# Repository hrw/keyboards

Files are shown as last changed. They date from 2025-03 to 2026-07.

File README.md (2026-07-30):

Here I plan to keep information about keyboards I worked on.

# [Alicja v1](alicja-v1/)

Yet another fork of fork of fork with Alice like layout.

[Blog post](https://marcin.juszkiewicz.com.pl/2025/03/09/i-built-my-first-mechanical-keyboard/)

Keyboard features:

- Handwired
- two encoders
- UltimatePico as MCU
- QMK with VIA.

Built only one copy. Dead keyboard, dead project.

# [Alicja v2](alicja-v2/)

[Blog post](https://marcin.juszkiewicz.com.pl/2026/07/29/new-keyboard-alicja-v2/)

Keyboard features:

- PCB
- hotswap
- encoder
- 5-way switch
- stabilisers
- RP2040 Stamp as MCU
- QMK with VIA
- connector with spare GPIO lines and power

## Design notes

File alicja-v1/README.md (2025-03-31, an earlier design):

# Alicja

First was TGR Alice, then [@FateNozomi](https://github.com/FateNozomi) created [Arisu](https://github.com/FateNozomi/arisu-pcb).
Next was [@floookay](https://github.com/floookay) with his [Adelheid](https://github.com/floookay/adelheid).

Then I took his keyboard and modified into what I call Alicja (Alice in Polish).

## First prototype

[Blog: "I built my first mechanical keyboard"](https://marcin.juszkiewicz.com.pl/2025/03/09/i-built-my-first-mechanical-keyboard/)

As simple as possible:
- 3d printed switch plate (two pieces mounted with each other)
- no PCB, no case
- UltimatePico as controller
- Redragon brown switches
- mix of keycaps from Aliexpress and random keyboards
- no stabilizers

### Photos

Capslock key is mapped as Fn.

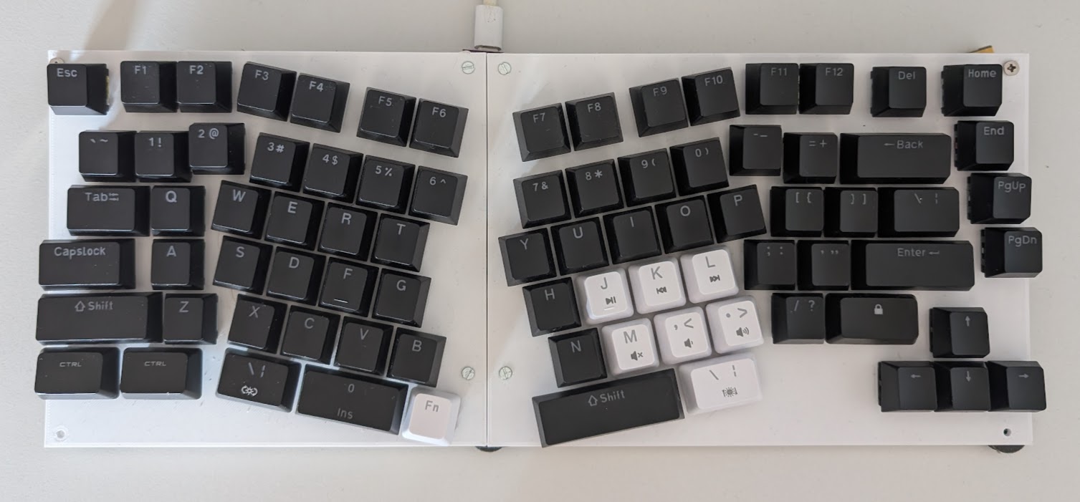
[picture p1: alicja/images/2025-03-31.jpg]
alicja

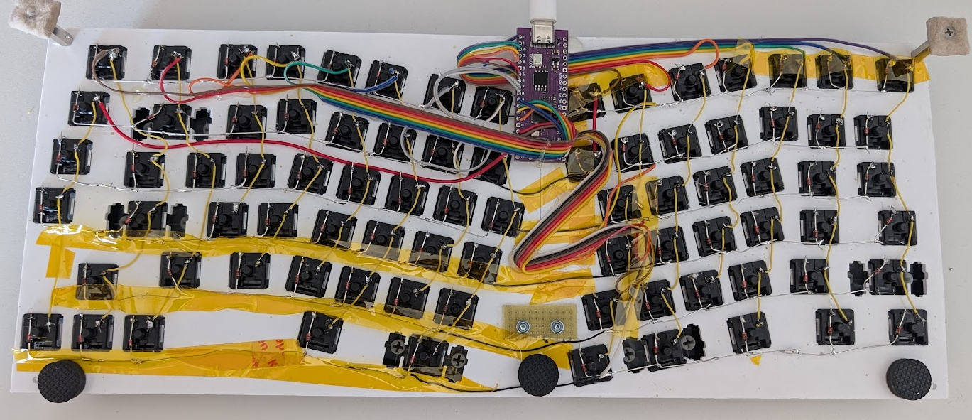
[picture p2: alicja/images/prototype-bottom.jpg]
bottom


### Changes compared to Adelheid

I did some changes to Adelheid keyboard layout:

- added 1.5u Meta key
- 2u Backspace
- 1.5u Backslash

[Keyboard Layout Editor](https://www.keyboard-layout-editor.com/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'&_c=%23777777&f:3&w:2.25%3B&=%E2%86%B5%20Enter%3B&@_c=%23aaaaaa&w:2.25%3B&=%E2%87%A7%20Shift&_c=%23cccccc&f:5%3B&=Z&_x:10.2&f:4%3B&=%3F%0A%2F%2F&_c=%23aaaaaa&f:3&w:1.75%3B&=%E2%87%A7%20Shift%3B&@_y:-0.75&x:16.45&c=%23777777&f:6%3B&=%E2%86%91%3B&@_y:-0.25&c=%23aaaaaa&f:3&w:1.5%3B&=Control&_w:1.5%3B&=Meta%3B&@_y:-0.75&x:15.45&c=%23777777&f:6%3B&=%E2%86%90&=%E2%86%93&=%E2%86%92%3B&@_rx:10&y:0.25&x:-7.5&c=%23cccccc&f:3%3B&=F2&_x:9.5%3B&=F11%3B&@_y:0.09999999999999987&x:-7.25&f:4%3B&=%2F@%0A2&_x:8.95%3B&=%2F_%0A-%3B&@_r:12&rx:8.5&ry:3.5&y:-2.25&x:-5.35&f:3%3B&=F3&=F4&_x:0.25%3B&=F5&=F6%3B&@_y:0.25&x:-4.85&f:4%3B&=%23%0A3&=$%0A4&=%25%0A5&=%5E%0A6%3B&@_x:-5.35&f:5%3B&=W&=E&=R&=T%3B&@_x:-5.1%3B&=S&=D&_n:true%3B&=F&=G%3B&@_x:-4.6%3B&=X&=C&=V&=B%3B&@_x:-4.6&c=%23aaaaaa&f:3&w:1.5%3B&=Alt&_c=%23cccccc&p=SPACE&a:7&w:2%3B&=&_c=%23aaaaaa&a:4%3B&=Fn%3B&@_r:-12&ry:3.25&y:-2.05&x:0.5500000000000007&c=%23cccccc%3B&=F7&=F8&_x:0.25%3B&=F9&=F10%3B&@_y:0.25&x:0.3000000000000007&f:4%3B&=%2F&%0A7&=*%0A8&=(%0A9&=)%0A0%3B&@_x:-0.1999999999999993&f:5%3B&=Y&=U&=I&=O&=P%3B&@_x:0.05000000000000071%3B&=H&_n:true%3B&=J&=K&=L%3B&@_x:0.3000000000000007%3B&=N&=M&_f:4%3B&=%3C%0A,&=%3E%0A.%3B&@_x:-0.1999999999999993&a:7&f:3&w:2.75%3B&=&_c=%23aaaaaa&a:4&w:1.5%3B&=Alt%20Gr)

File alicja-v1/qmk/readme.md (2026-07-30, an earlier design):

# Alicja

Alicja

*Yet another clone of Alice/Arisu/Adelheid.*

* Keyboard Maintainer: [Marcin Juszkiewicz](https://marcin.juszkiewicz.com.pl/)
* Hardware Supported: *I used Ultimate Pico, other RP2040 should be fine*
* Hardware Availability: *DIY*

Make example for this keyboard (after setting up your build environment):

    make alicja:default

See the [build environment setup](https://docs.qmk.fm/#/getting_started_build_tools)
and the [make instructions](https://docs.qmk.fm/#/getting_started_make_guide)
for more information.
Brand new to QMK? Start with our [Complete Newbs Guide](https://docs.qmk.fm/#/newbs).
ttps://docs.qmk.fm/#/newbs).

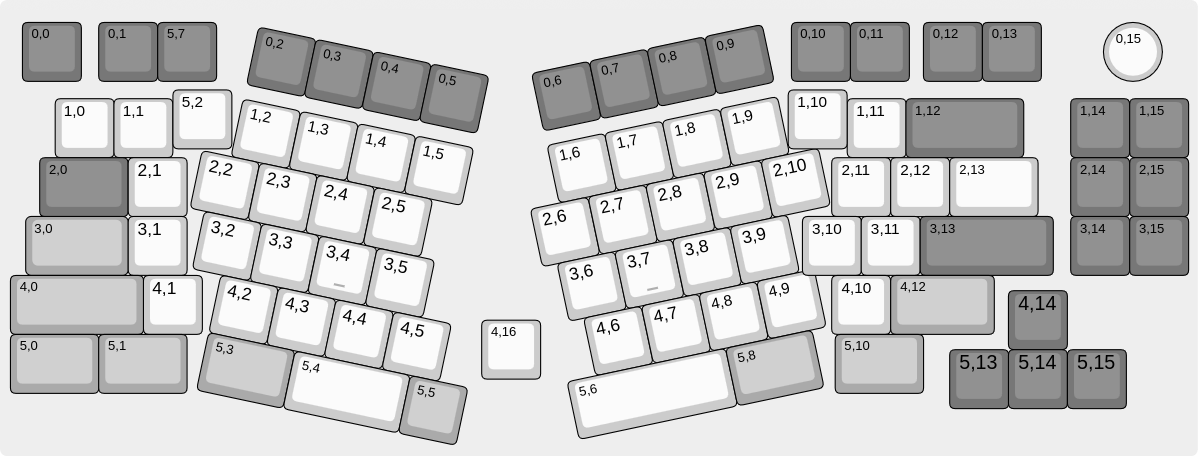
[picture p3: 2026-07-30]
alicja-v2/kle-ng/kle-layout-internal.png

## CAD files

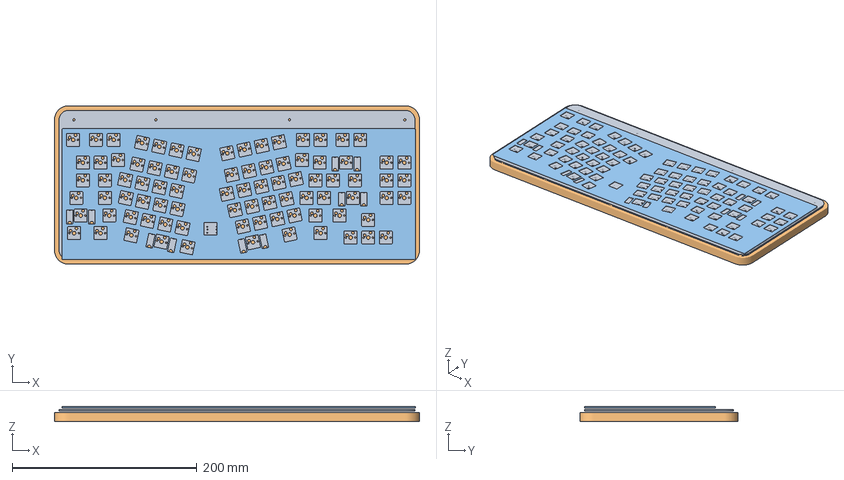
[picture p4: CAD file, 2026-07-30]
alicja-v2/case/Alicja v2.FCStd
394.8 x 171.3 x 16.5 mm
Pcb_63e7
keyboard-plate

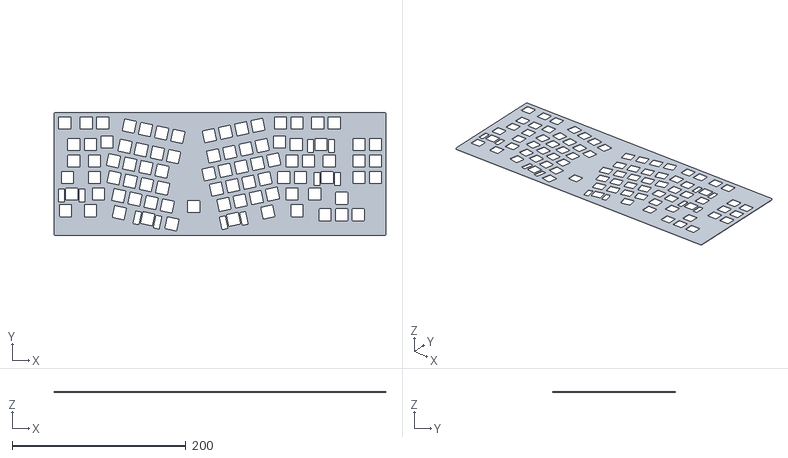
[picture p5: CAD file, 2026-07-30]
alicja-v2/kle-ng/keyboard-plate.stl
382.5 x 141.4 x 1.50

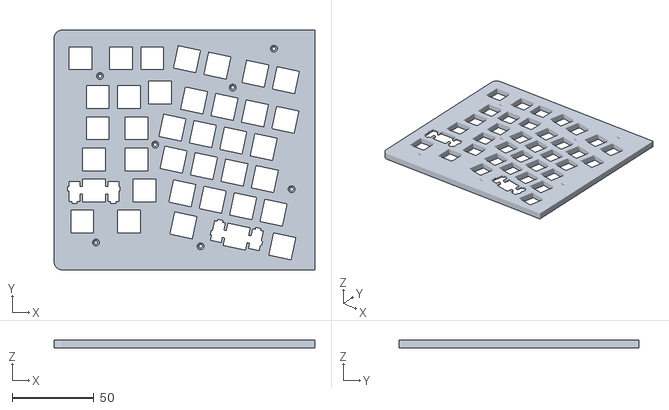
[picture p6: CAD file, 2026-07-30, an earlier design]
alicja-v1/case/drugie podejście/lewa.stl
159.9 x 147.0 x 5.00

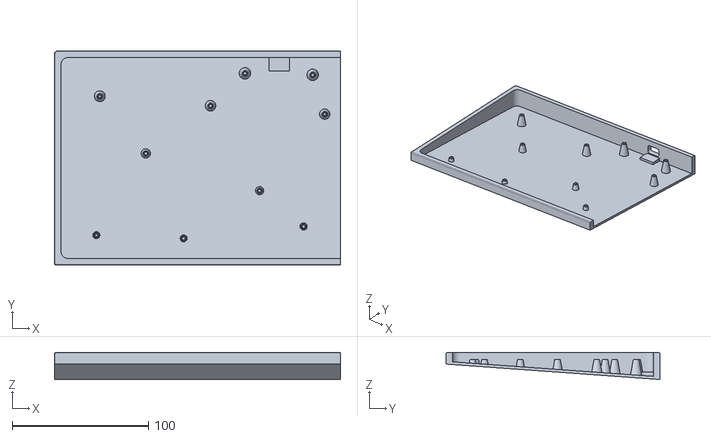
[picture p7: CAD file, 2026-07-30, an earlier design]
alicja-v1/case/drugie podejście/dol - lewa.stl
209.9 x 157.0 x 19.8

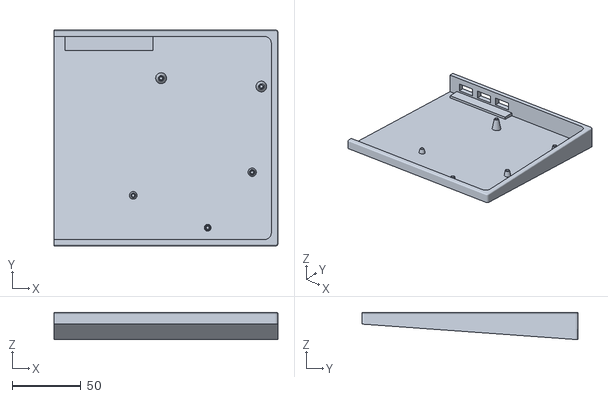
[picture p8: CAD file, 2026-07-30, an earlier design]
alicja-v1/case/drugie podejście/dol - prawa.stl
162.6 x 157.0 x 19.8

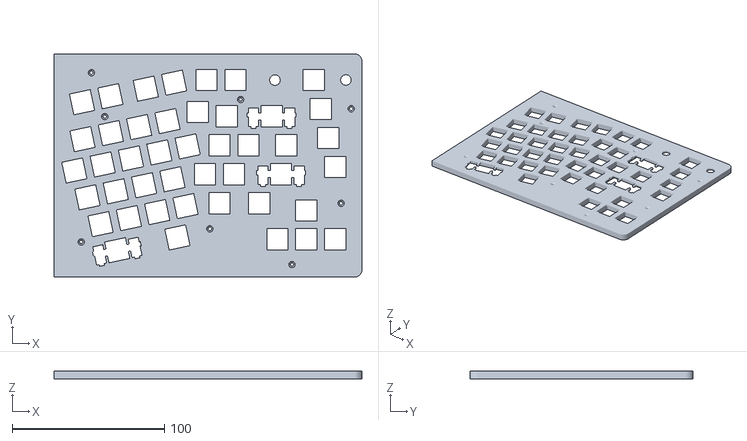
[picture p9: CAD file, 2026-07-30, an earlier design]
alicja-v1/case/drugie podejście/prawa.stl
202.6 x 147.0 x 5.00

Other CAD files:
alicja-v2/kle-ng/keyboard-plate.dxf

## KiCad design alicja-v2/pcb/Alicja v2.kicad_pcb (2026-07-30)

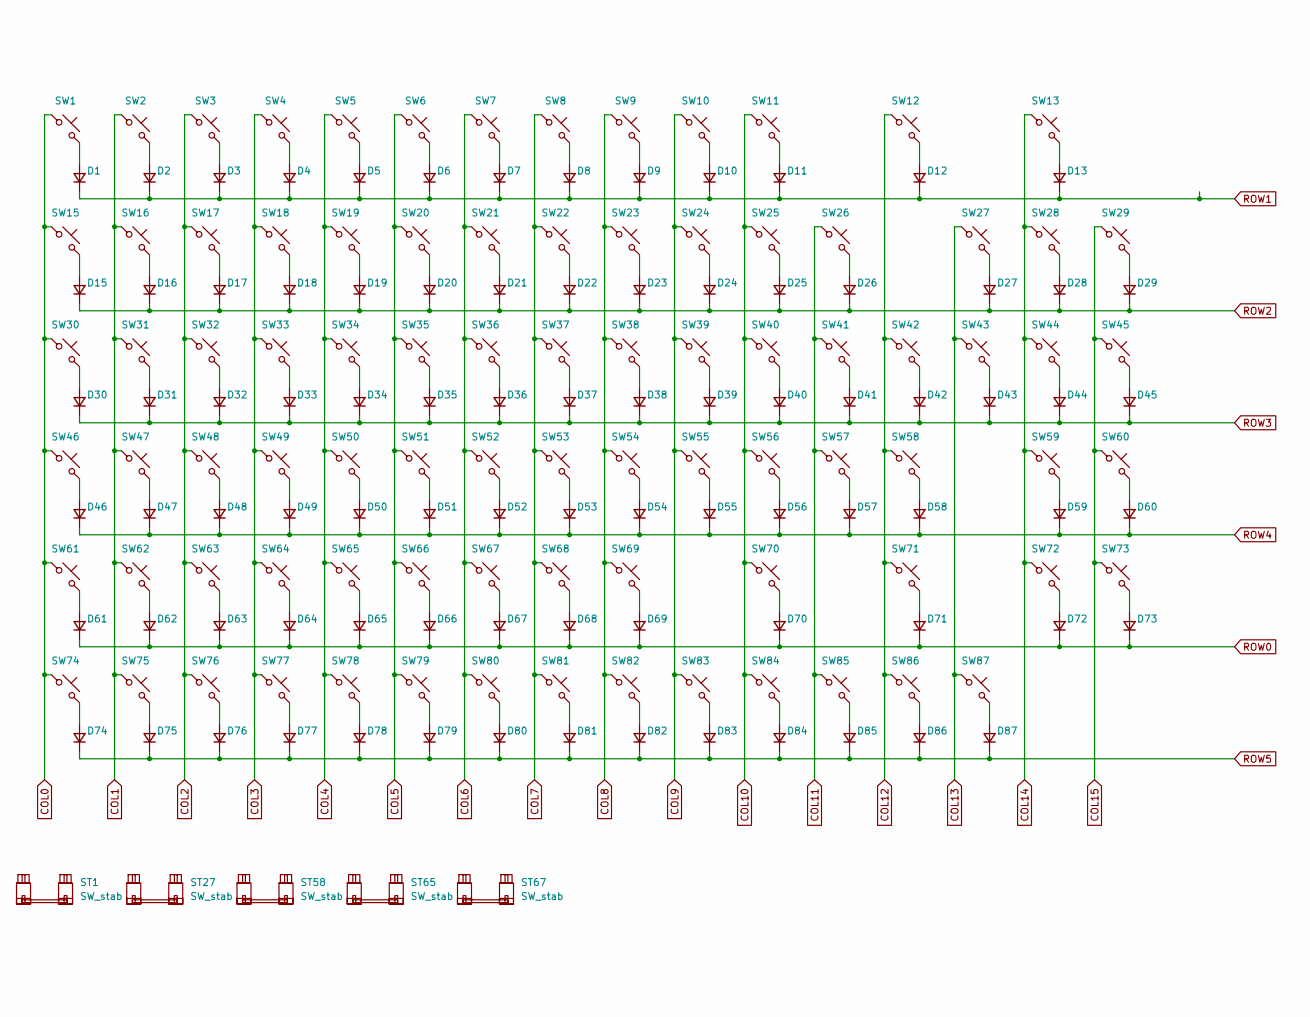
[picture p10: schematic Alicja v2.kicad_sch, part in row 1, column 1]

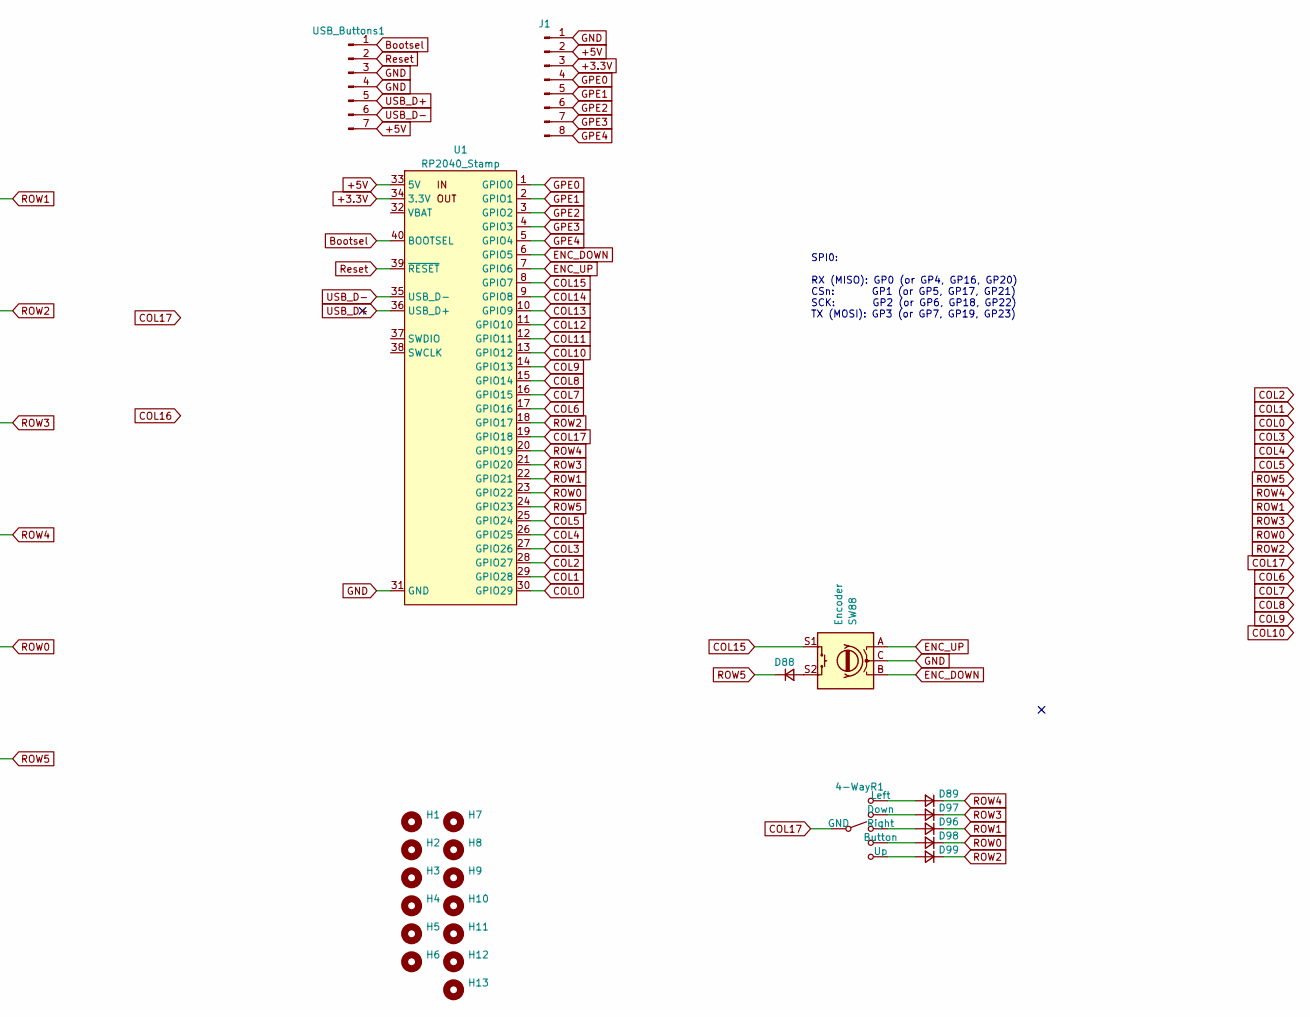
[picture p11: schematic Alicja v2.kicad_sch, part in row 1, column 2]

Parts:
4-WayR1: 4-Way Ali
D1, D2, D3, D4, D5, D6, D7, D8, D9, D10, D11, D12, D13, D15, D16, D17, D18, D19, D20, D21, D22, D23, D24, D25, D26, D27, D28, D29, D30, D31, D32, D33, D34, D35, D36, D37, D38, D39, D40, D41, D42, D43, D44, D45, D46, D47, D48, D49, D50, D51, D52, D53, D54, D55, D56, D57, D58, D59, D60, D61, D62, D63, D64, D65, D66, D67, D68, D69, D70, D71, D72, D73, D74, D75, D76, D77, D78, D79, D80, D81, D82, D83, D84, D85, D86, D87, D88, D89, D96, D97, D98, D99: D; D_1206_3216Metric_Pad1.42x1.75mm_HandSolder
H1, H2, H3, H4, H5, H6, H7, H8, H9, H10, H11, H12, H13: MountingHole; MountingHole_2.5mm
J1: Conn_01x08_Pin; JST_XH_B8B-XH-AM_1x08_P2.50mm_Vertical_SMD
ST1, ST27, ST58, ST65, ST67: SW_stab; Stabilizer_Cherry_MX_2.00u
SW1, SW27: SW_Push; SW_Hotswap_Kailh_MX_2.25u
SW2, SW3, SW4, SW5, SW6, SW7, SW8, SW9, SW10, SW11, SW13, SW16, SW17, SW18, SW19, SW20, SW21, SW22, SW23, SW24, SW25, SW26, SW28, SW29, SW31, SW32, SW33, SW34, SW35, SW36, SW37, SW38, SW39, SW40, SW41, SW42, SW44, SW45, SW46, SW47, SW48, SW49, SW50, SW51, SW52, SW53, SW54, SW55, SW56, SW57, SW59, SW60, SW63, SW66, SW68, SW71, SW72, SW73, SW74, SW75, SW76, SW77, SW78, SW79, SW80, SW81, SW82, SW83, SW84, SW85, SW86, SW87: SW_Push; SW_Hotswap_Kailh_MX_1.00u
SW12: SW_Push; SW_Hotswap_Kailh_MX_1.75u
SW15: SW_Push; SW_Hotswap_Kailh_MX_1.25u
SW30, SW43, SW61, SW62, SW64, SW69, SW70: SW_Push; SW_Hotswap_Kailh_MX_1.50u
SW58, SW65: SW_Push; SW_Hotswap_Kailh_MX_2.00u
SW67: SW_Push; SW_Hotswap_Kailh_MX_2.75u
SW88: Encoder; RotaryEncoder_Alps_EC11E-Switch_Vertical_H20mm_SMD
U1: RP2040_Stamp; RP2xxx_Stamp_SMD
USB_Buttons1: Conn_01x07_Pin; JST_XH_B8B-XH-AM_1x07_P2.50mm_Vertical_SMD

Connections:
+3.3V: J1.3, U1.34 (3.3V)
+5V: J1.2, U1.33 (5V), USB_Buttons1.7
Bootsel: U1.40 (BOOTSEL), USB_Buttons1.1
COL0: SW1.1, SW15.1, SW30.1, SW46.1, SW61.1, SW74.1, U1.30 (GPIO29)
COL1: SW2.1, SW16.1, SW31.1, SW47.1, SW62.1, SW75.1, U1.29 (GPIO28)
COL2: SW3.1, SW17.1, SW32.1, SW48.1, SW63.1, SW76.1, U1.28 (GPIO27)
COL3: SW4.1, SW18.1, SW33.1, SW49.1, SW64.1, SW77.1, U1.27 (GPIO26)
COL4: SW5.1, SW19.1, SW34.1, SW50.1, SW65.1, SW78.1, U1.26 (GPIO25)
COL5: SW6.1, SW20.1, SW35.1, SW51.1, SW66.1, SW79.1, U1.25 (GPIO24)
COL6: SW7.1, SW21.1, SW36.1, SW52.1, SW67.1, SW80.1, U1.17 (GPIO16)
COL7: SW8.1, SW22.1, SW37.1, SW53.1, SW68.1, SW81.1, U1.16 (GPIO15)
COL8: SW9.1, SW23.1, SW38.1, SW54.1, SW69.1, SW82.1, U1.15 (GPIO14)
COL9: SW10.1, SW24.1, SW39.1, SW55.1, SW83.1, U1.14 (GPIO13)
COL10: SW11.1, SW25.1, SW40.1, SW56.1, SW70.1, SW84.1, U1.13 (GPIO12)
COL11: SW26.1, SW41.1, SW57.1, SW85.1, U1.12 (GPIO11)
COL12: SW12.1, SW42.1, SW58.1, SW71.1, SW86.1, U1.11 (GPIO10)
COL13: SW27.1, SW43.1, SW87.1, U1.10 (GPIO9)
COL14: SW13.1, SW28.1, SW44.1, SW59.1, SW72.1, U1.9 (GPIO8)
COL15: SW29.1, SW45.1, SW60.1, SW73.1, SW88.S1, U1.8 (GPIO7)
COL17: 4-WayR1.6 (GND), U1.19 (GPIO18)
ENC_DOWN: SW88.B, U1.6 (GPIO5)
ENC_UP: SW88.A, U1.7 (GPIO6)
GND: J1.1, SW88.C, U1.31 (GND), USB_Buttons1.3, USB_Buttons1.4
GPE0: J1.4, U1.1 (GPIO0)
GPE1: J1.5, U1.2 (GPIO1)
GPE2: J1.6, U1.3 (GPIO2)
GPE3: J1.7, U1.4 (GPIO3)
GPE4: J1.8, U1.5 (GPIO4)
unnamed: 4-WayR1.4 (Button), D98.2 (A)
unnamed: 4-WayR1.2 (Down), D97.2 (A)
unnamed: 4-WayR1.1 (Left), D89.2 (A)
unnamed: 4-WayR1.3 (Right), D96.2 (A)
unnamed: 4-WayR1.5 (Up), D99.2 (A)
unnamed: D1.2 (A), SW1.2
unnamed: D2.2 (A), SW2.2
unnamed: D3.2 (A), SW3.2
unnamed: D4.2 (A), SW4.2
unnamed: D5.2 (A), SW5.2
unnamed: D6.2 (A), SW6.2
unnamed: D7.2 (A), SW7.2
unnamed: D8.2 (A), SW8.2
unnamed: D9.2 (A), SW9.2
unnamed: D10.2 (A), SW10.2
unnamed: D11.2 (A), SW11.2
unnamed: D12.2 (A), SW12.2
unnamed: D13.2 (A), SW13.2
unnamed: D15.2 (A), SW15.2
unnamed: D16.2 (A), SW16.2
unnamed: D17.2 (A), SW17.2
unnamed: D18.2 (A), SW18.2
unnamed: D19.2 (A), SW19.2
unnamed: D20.2 (A), SW20.2
unnamed: D21.2 (A), SW21.2
unnamed: D22.2 (A), SW22.2
unnamed: D23.2 (A), SW23.2
unnamed: D24.2 (A), SW24.2
unnamed: D25.2 (A), SW25.2
unnamed: D26.2 (A), SW26.2
unnamed: D27.2 (A), SW27.2
unnamed: D28.2 (A), SW28.2
unnamed: D29.2 (A), SW29.2
unnamed: D30.2 (A), SW30.2
unnamed: D31.2 (A), SW31.2
unnamed: D32.2 (A), SW32.2
unnamed: D33.2 (A), SW33.2
unnamed: D34.2 (A), SW34.2
unnamed: D35.2 (A), SW35.2
unnamed: D36.2 (A), SW36.2
unnamed: D37.2 (A), SW37.2
unnamed: D38.2 (A), SW38.2
unnamed: D39.2 (A), SW39.2
unnamed: D40.2 (A), SW40.2
unnamed: D41.2 (A), SW41.2
unnamed: D42.2 (A), SW42.2
unnamed: D43.2 (A), SW43.2
unnamed: D44.2 (A), SW44.2
unnamed: D45.2 (A), SW45.2
unnamed: D46.2 (A), SW46.2
unnamed: D47.2 (A), SW47.2
unnamed: D48.2 (A), SW48.2
unnamed: D49.2 (A), SW49.2
unnamed: D50.2 (A), SW50.2
unnamed: D51.2 (A), SW51.2
unnamed: D52.2 (A), SW52.2
unnamed: D53.2 (A), SW53.2
unnamed: D54.2 (A), SW54.2
unnamed: D55.2 (A), SW55.2
unnamed: D56.2 (A), SW56.2
unnamed: D57.2 (A), SW57.2
unnamed: D58.2 (A), SW58.2
unnamed: D59.2 (A), SW59.2
unnamed: D60.2 (A), SW60.2
unnamed: D61.2 (A), SW61.2
unnamed: D62.2 (A), SW62.2
unnamed: D63.2 (A), SW63.2
unnamed: D64.2 (A), SW64.2
unnamed: D65.2 (A), SW65.2
unnamed: D66.2 (A), SW66.2
unnamed: D67.2 (A), SW67.2
unnamed: D68.2 (A), SW68.2
unnamed: D69.2 (A), SW69.2
unnamed: D70.2 (A), SW70.2
unnamed: D71.2 (A), SW71.2
unnamed: D72.2 (A), SW72.2
unnamed: D73.2 (A), SW73.2
unnamed: D74.2 (A), SW74.2
unnamed: D75.2 (A), SW75.2
unnamed: D76.2 (A), SW76.2
unnamed: D77.2 (A), SW77.2
unnamed: D78.2 (A), SW78.2
unnamed: D79.2 (A), SW79.2
unnamed: D80.2 (A), SW80.2
unnamed: D81.2 (A), SW81.2
unnamed: D82.2 (A), SW82.2
unnamed: D83.2 (A), SW83.2
unnamed: D84.2 (A), SW84.2
unnamed: D85.2 (A), SW85.2
unnamed: D86.2 (A), SW86.2
unnamed: D87.2 (A), SW87.2
unnamed: D88.2 (A), SW88.S2
ROW0: D61.1 (K), D62.1 (K), D63.1 (K), D64.1 (K), D65.1 (K), D66.1 (K), D67.1 (K), D68.1 (K), D69.1 (K), D70.1 (K), D71.1 (K), D72.1 (K), D73.1 (K), D98.1 (K), U1.23 (GPIO22)
ROW1: D1.1 (K), D2.1 (K), D3.1 (K), D4.1 (K), D5.1 (K), D6.1 (K), D7.1 (K), D8.1 (K), D9.1 (K), D10.1 (K), D11.1 (K), D12.1 (K), D13.1 (K), D96.1 (K), U1.22 (GPIO21)
ROW2: D15.1 (K), D16.1 (K), D17.1 (K), D18.1 (K), D19.1 (K), D20.1 (K), D21.1 (K), D22.1 (K), D23.1 (K), D24.1 (K), D25.1 (K), D26.1 (K), D27.1 (K), D28.1 (K), D29.1 (K), D99.1 (K), U1.18 (GPIO17)
ROW3: D30.1 (K), D31.1 (K), D32.1 (K), D33.1 (K), D34.1 (K), D35.1 (K), D36.1 (K), D37.1 (K), D38.1 (K), D39.1 (K), D40.1 (K), D41.1 (K), D42.1 (K), D43.1 (K), D44.1 (K), D45.1 (K), D97.1 (K), U1.21 (GPIO20)
ROW4: D46.1 (K), D47.1 (K), D48.1 (K), D49.1 (K), D50.1 (K), D51.1 (K), D52.1 (K), D53.1 (K), D54.1 (K), D55.1 (K), D56.1 (K), D57.1 (K), D58.1 (K), D59.1 (K), D60.1 (K), D89.1 (K), U1.20 (GPIO19)
ROW5: D74.1 (K), D75.1 (K), D76.1 (K), D77.1 (K), D78.1 (K), D79.1 (K), D80.1 (K), D81.1 (K), D82.1 (K), D83.1 (K), D84.1 (K), D85.1 (K), D86.1 (K), D87.1 (K), D88.1 (K), U1.24 (GPIO23)
Reset: U1.39 (~RESET), USB_Buttons1.2
USB_D+: U1.36 (USB_D+), USB_Buttons1.5
USB_D-: U1.35 (USB_D-), USB_Buttons1.6

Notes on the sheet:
SPI0: RX (MISO): GP0 (or GP4, GP16, GP20) CSn: GP1 (or GP5, GP17, GP21) SCK: GP2 (or GP6, GP18, GP22) TX (MOSI): GP3 (or GP7, GP19, GP23)

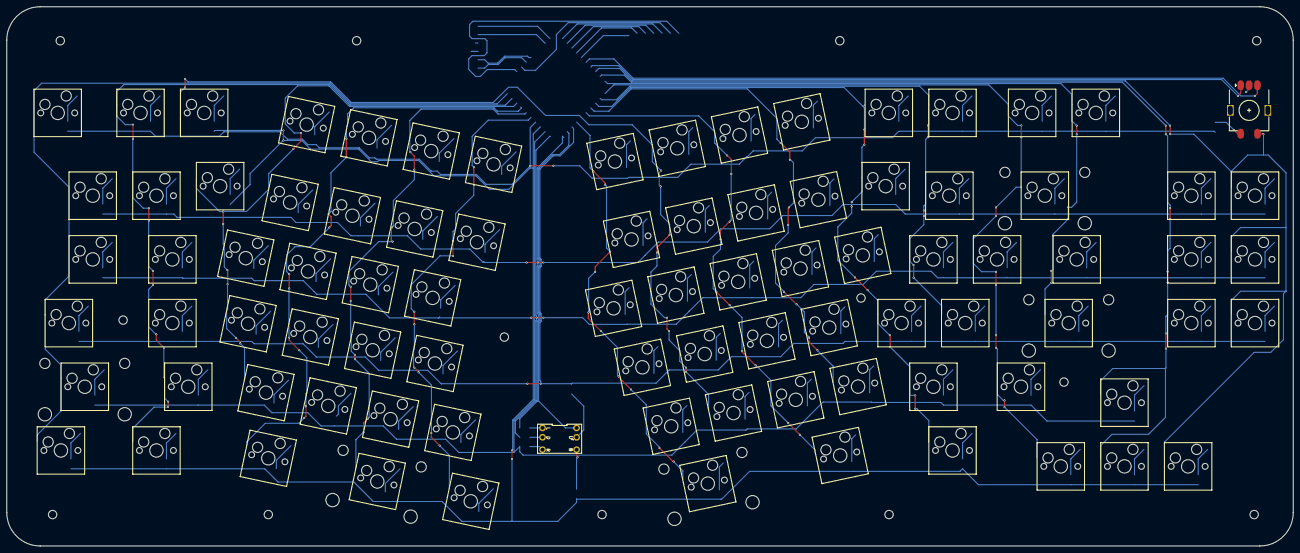
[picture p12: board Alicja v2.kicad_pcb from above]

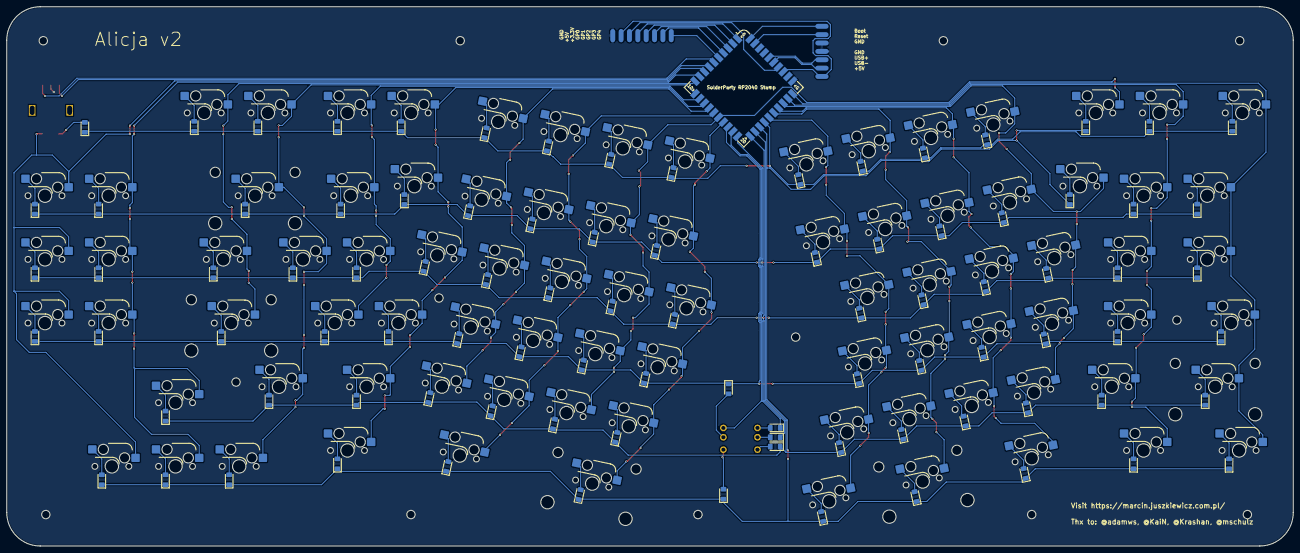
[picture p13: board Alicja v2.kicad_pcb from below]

Board: 2 copper layers, 384.8 x 161.3 mm, 201 parts (94 on the bottom side), 129 nets.

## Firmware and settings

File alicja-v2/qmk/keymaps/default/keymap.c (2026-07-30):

// Copyright 2023 QMK
// SPDX-License-Identifier: GPL-2.0-or-later

#include QMK_KEYBOARD_H

#include <stdbool.h>
#include <stdint.h>

bool process_record_user(uint16_t keycode, keyrecord_t *record) {
// If console is enabled, it will print the matrix position and status of each
// key pressed
#ifdef CONSOLE_ENABLE

    const char *key_name = get_keycode_string(keycode);
    uprintf("kc: 0x%04X (%-7s), row: %2u, col: %2u, pressed: %u, "
            "time: %5u, int: %u, count: %u\n",
            keycode, key_name,
            record->event.key.row, record->event.key.col,
            record->event.pressed, record->event.time,
            record->tap.interrupted, record->tap.count);
#endif
    return true;
}

const uint16_t PROGMEM keymaps[][MATRIX_ROWS][MATRIX_COLS] = {
    [0] = LAYOUT(
      /*              0         1        2        3        4        5            6        7        8         9        10        11        12        13        14        15 */
      /* 0, pcb 5 */  KC_ESC,   KC_F1,   KC_F3,   KC_F4,   KC_F5,   KC_F6,       KC_F7,   KC_F8,   KC_F9,    KC_F10,  KC_F11,   KC_F12,   KC_F13,   KC_F14,             KC_MUTE,
      /* 1, pcb 4 */  KC_GRAVE, KC_1,    KC_3,    KC_4,    KC_5,    KC_6,        KC_7,    KC_8,    KC_9,     KC_0,    KC_MINUS, KC_EQL,   KC_BSPC,            KC_HOME,  KC_END,
      /* 2, pcb 3 */  KC_TAB,   KC_Q,    KC_W,    KC_E,    KC_R,    KC_T,        KC_Y,    KC_U,    KC_I,     KC_O,    KC_P,     KC_LBRC,  KC_RBRC,  KC_BSLS,  KC_INS,   KC_PGUP,
      /* 3, pcb 2 */  MO(1),    KC_A,    KC_S,    KC_D,    KC_F,    KC_G,        KC_H,    KC_J,    KC_K,     KC_L,    KC_SCLN,  KC_QUOTE,           KC_ENTER, KC_DEL,   KC_PGDN,
      /* 4, pcb 1 */  KC_LSFT,  KC_Z,    KC_X,    KC_C,    KC_V,    KC_B,        KC_N,    KC_M,    KC_COMMA, KC_DOT,  KC_SLASH,           KC_RSFT,            KC_UP,
      /* 5, pcb 0 */  KC_LCTL,  KC_LGUI, KC_2,    KC_LALT, KC_SPC,  KC_LGUI,     KC_SPC,  KC_F2,   KC_RALT,           KC_RCTL,            KC_LEFT,            KC_DOWN,  KC_RGHT,
      /* 5-way    */  KC_TRNS,  KC_TRNS, KC_TRNS, KC_TRNS, KC_TRNS),

    [1] = LAYOUT(
                      QK_BOOT,  KC_TRNS, KC_TRNS, KC_TRNS, KC_TRNS, KC_TRNS,     KC_TRNS, KC_TRNS, KC_TRNS,  KC_TRNS, KC_TRNS,  KC_TRNS,  KC_TRNS,  KC_TRNS,            KC_MPLY,
                      KC_TRNS,  KC_TRNS, KC_TRNS, KC_TRNS, KC_TRNS, KC_TRNS,     KC_TRNS, KC_TRNS, KC_TRNS,  KC_TRNS, KC_TRNS,  KC_TRNS,  KC_TRNS,           KC_TRNS,   KC_TRNS,
                      KC_TRNS,  KC_TRNS, KC_TRNS, KC_TRNS, KC_TRNS, KC_TRNS,     KC_TRNS, KC_TRNS, KC_TRNS,  KC_TRNS, KC_TRNS,  KC_TRNS,  KC_TRNS,  KC_TRNS, KC_TRNS,   KC_TRNS,
                      KC_TRNS,  KC_TRNS, KC_TRNS, KC_TRNS, KC_TRNS, KC_TRNS,     KC_TRNS, KC_MPLY, KC_MPRV,  KC_MNXT, KC_TRNS,  KC_TRNS,            KC_TRNS, KC_TRNS,   KC_TRNS,
                      KC_TRNS,  KC_TRNS, KC_TRNS, KC_TRNS, KC_TRNS, KC_TRNS,     KC_TRNS, KC_MUTE, KC_VOLD,  KC_VOLU, KC_TRNS,            KC_TRNS,           KC_TRNS,
                      KC_TRNS,  KC_TRNS, KC_TRNS, KC_TRNS, KC_TRNS, KC_TRNS,     KC_TRNS, KC_TRNS, KC_TRNS,           KC_TRNS,            KC_TRNS,  KC_TRNS, KC_TRNS,
      /* 5-way    */  KC_TRNS,  KC_TRNS, KC_TRNS, KC_TRNS, KC_TRNS)
};

#if defined(ENCODER_MAP_ENABLE)

#define NUM_DIRECTIONS 2

const uint16_t PROGMEM encoder_map[][NUM_ENCODERS][NUM_DIRECTIONS] = {
    [0] = { ENCODER_CCW_CW(KC_VOLD, KC_VOLU)  },
    [1] = { ENCODER_CCW_CW(KC_MPRV, KC_MNXT)  },
};

#endif

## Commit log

2025-03-31 alicja: add photo of current prototype
2025-03-31 alicja: keymap for VIA
    Layout which I use in prototype
2025-03-31 alicja: add JSON matrix file for VIA
    This file is needed to be able to remap keys using VIA website.
    I use USB vid/pid from Adelheid keyboard but with own matrix so this
    file is required.
2026-07-30 alicja v1: old files
    [dol - lewa.stl, dol - prawa.stl, lewa.stl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]
2026-07-30 Alicja v2: PCB in KiCAD
    [Alicja v2.kicad_pcb, Alicja v2.kicad_sch]
2026-07-30 Alicja v2: simple case designed in FreeCAD
    [Alicja v2.FCStd]
2026-07-30 Alicja v2: data for/from KLE NG
    [keyboard-plate.dxf, keyboard-plate.stl]
